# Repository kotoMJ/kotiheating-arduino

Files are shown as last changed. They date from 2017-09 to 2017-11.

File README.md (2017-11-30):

# kotiheating-arduino

IoT KotiHeating project for remote heating control realized with Arduino HW.

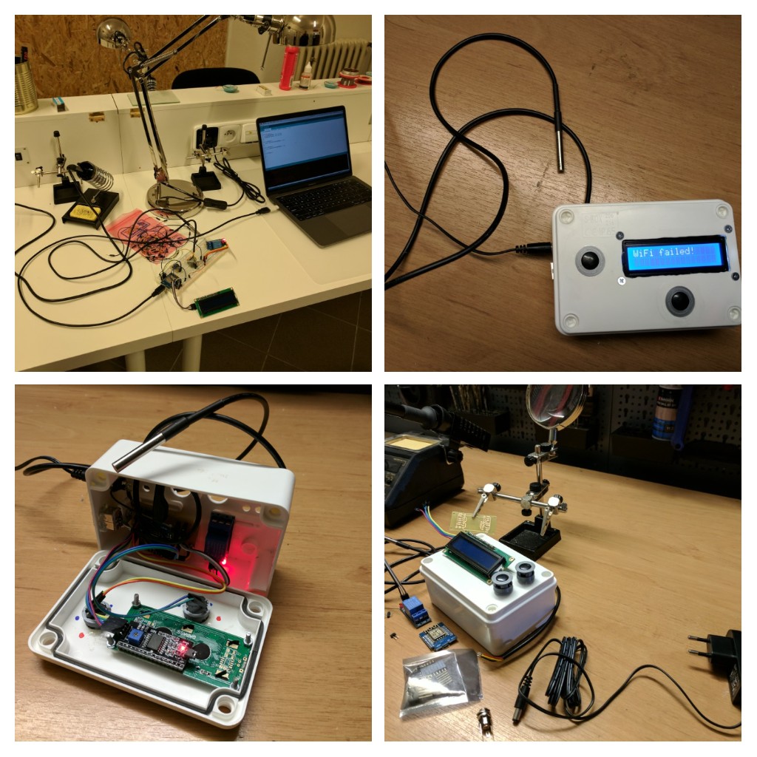
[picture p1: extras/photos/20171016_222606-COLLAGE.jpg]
KoTiHeating


## Functionality

KotiHeating offers 3 heating modes:
1) OFF - heating is set to non-freezing level (5°C)
2) MANUAL - allows set heating level from 18°C to 28°C
3) AUTOMATIC - reads temperature from locally saved matrix

## WiFi Connectivity

KotiHeating exposes following endpoints via WIFI:
- TBD.
- TBD.

## Internet Connectivity

Kotiheating is periodically connecting to server endpoint to update AUTOMATIC matrix 
and to save last known state of the device.

Server matrix can be changed on the server TBD.

Server expose last known state of the KotiHeating via API TBD.

### HTTPS connection

#### Cipher suite supported by device
Current solution is for chip ESP8266.
This chip supports TLS1.1 only and only in these two variants:
1)TLS_RSA_WITH_AES_256_CBC_SHA
2)TLS_RSA_WITH_AES_128_CBC_SHA

You can check your device running this program on it:
 `http.begin("https://www.howsmyssl.com/a/check", "4D 05 9F 78 25 B2 82 98 3A B9 4D 4D 41 71 FA D3 DF C4 65 B9");`

#### Cipher cuite supported by server
Then check which ciphers has been supported by server (kotopeky.cz in my case):
 
`nmap --script ssl-enum-ciphers -p 443 kotopeky.cz`
 
 If you find device's suite in the server's table, everything is ok.
 Otherwise you have to force server to support also device's cipher, or change device to fit server's cipher suite.
 
#### Key Fingerprint
 
If server's and device's cipher match. 
Then start connection using SHA1 fingerprint (look at the safari status bar for example).
In my case it's this:
 
 `http.begin("https://kotopeky.cz/api/kotinode/heating/status","63 FD D7 BB B4 A5 6C 00 57 0F 23 A2 FD 27 15 96 4A C2 4D 99");`

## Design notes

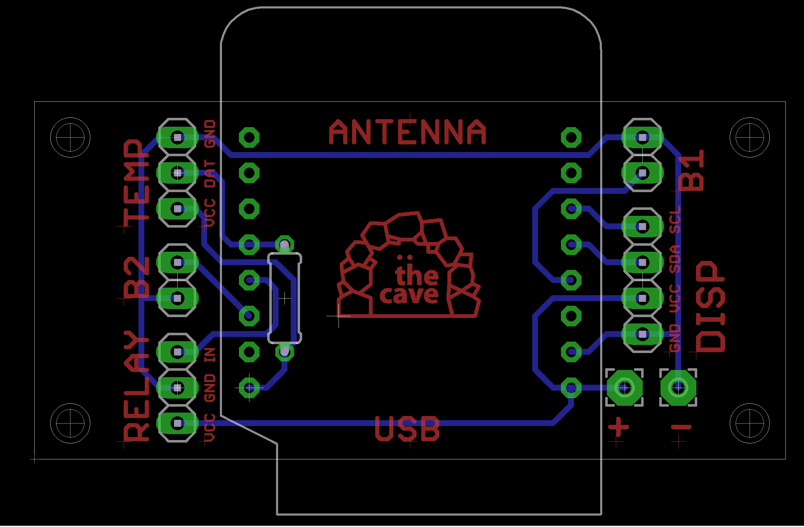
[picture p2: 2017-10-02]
extras/schema/heating_schema.png

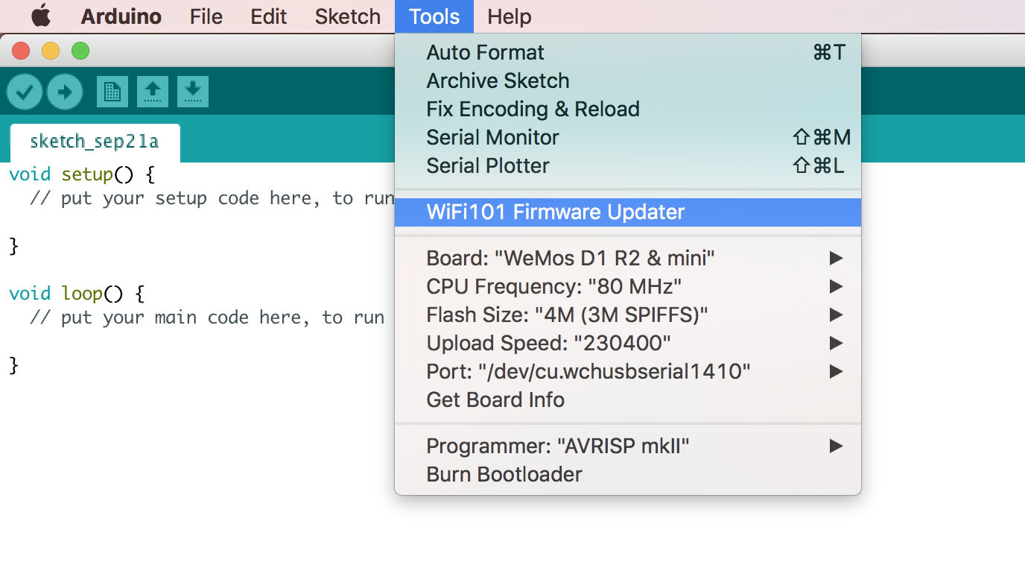
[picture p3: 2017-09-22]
extras/ArduinoToolsSettingsHeating.png

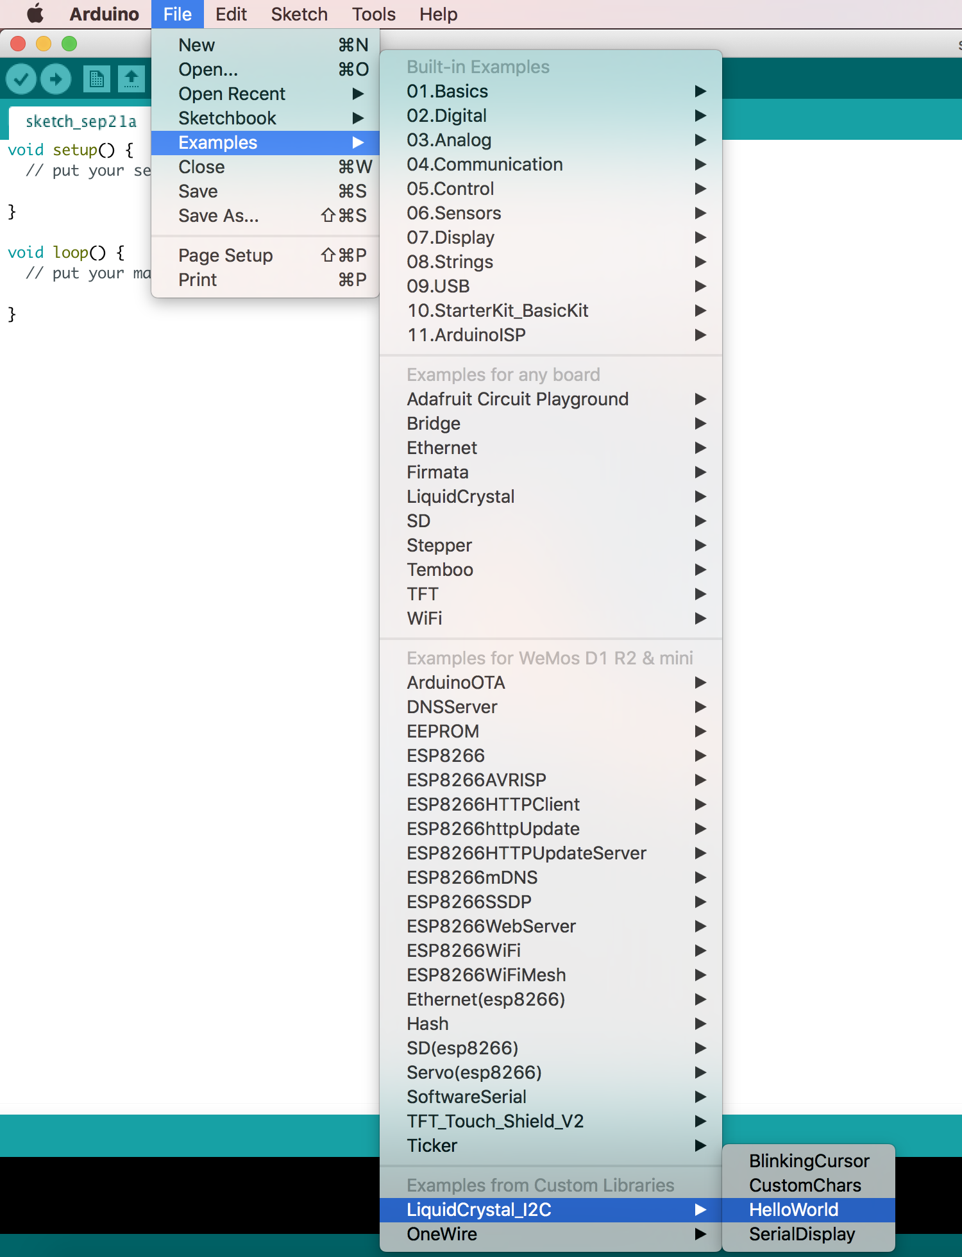
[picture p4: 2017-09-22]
extras/ArduinoExamplesDisplay.png

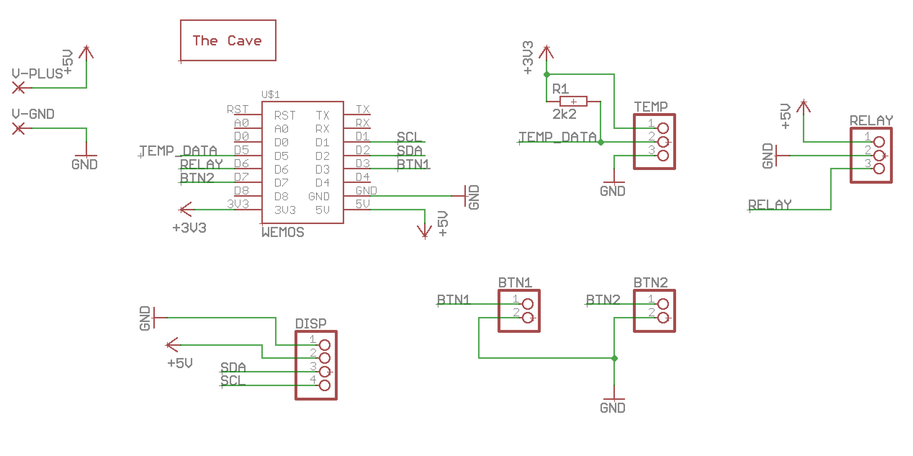
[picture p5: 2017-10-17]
extras/schema/kotiheating-arduino.png

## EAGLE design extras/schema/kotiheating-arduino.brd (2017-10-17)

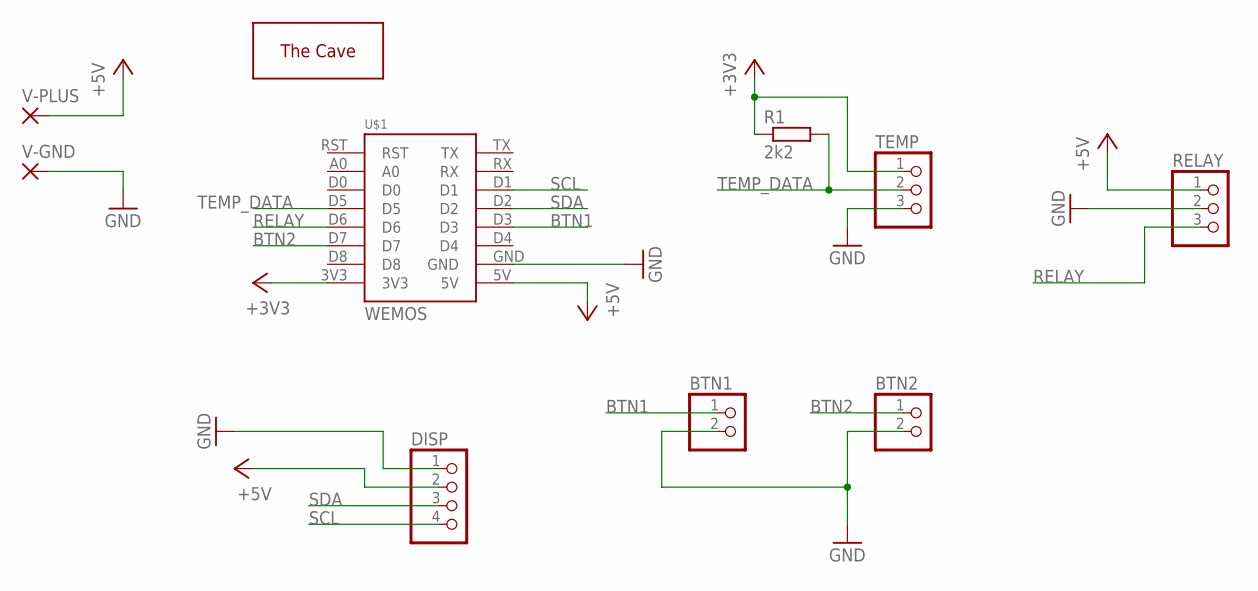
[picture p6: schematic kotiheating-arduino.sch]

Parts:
BTN1, BTN2: PINHD-1X2; 1X02
DISP: PINHD-1X4; 1X04
R1: 2k2; 0207/7
RELAY: PINHD-1X3; 1X03
TEMP: PINHD-1X3; 1X03
U$1: WEMOS
U$2: THECAVE_LOGO_COPPER_SMALL; LOGO_COPPER_SMALL
V-GND: WIREPAD2,54/0,9; 2,54/0,9
V-PLUS: WIREPAD2,54/0,9; 2,54/0,9

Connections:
+3V3: R1.1, TEMP.1, U$1.3V3
+5V: DISP.2, RELAY.1, U$1.5V, V-PLUS.1
BTN1: BTN1.1, U$1.D3
BTN2: BTN2.1, U$1.D7
GND: BTN1.2, BTN2.2, DISP.1, RELAY.2, TEMP.3, U$1.GND, V-GND.1
RELAY: RELAY.3, U$1.D6
SCL: DISP.4, U$1.D1
SDA: DISP.3, U$1.D2
TEMP_DATA: R1.2, TEMP.2, U$1.D5

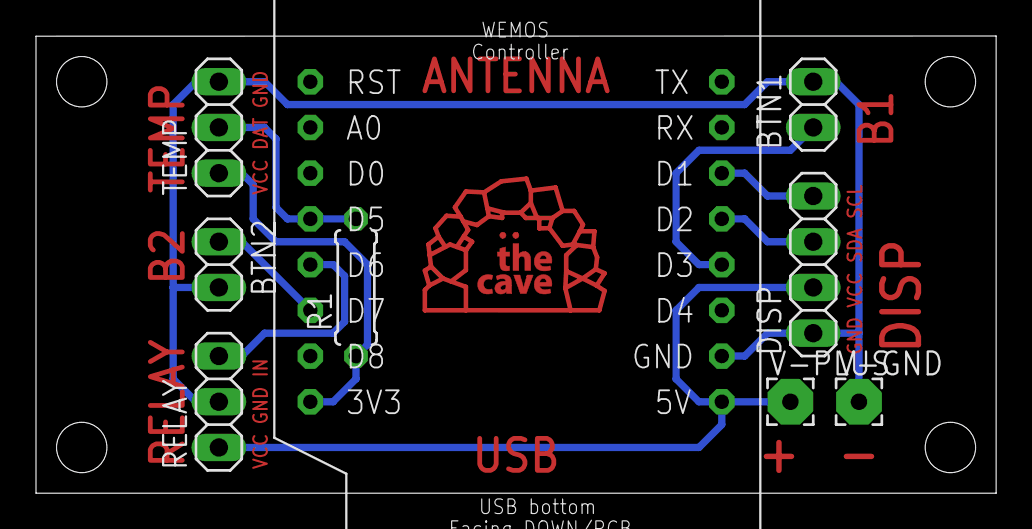
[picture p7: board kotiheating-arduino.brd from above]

Board: 2 copper layers, 53.3 x 25.4 mm, 10 parts (0 on the bottom side), 9 nets.

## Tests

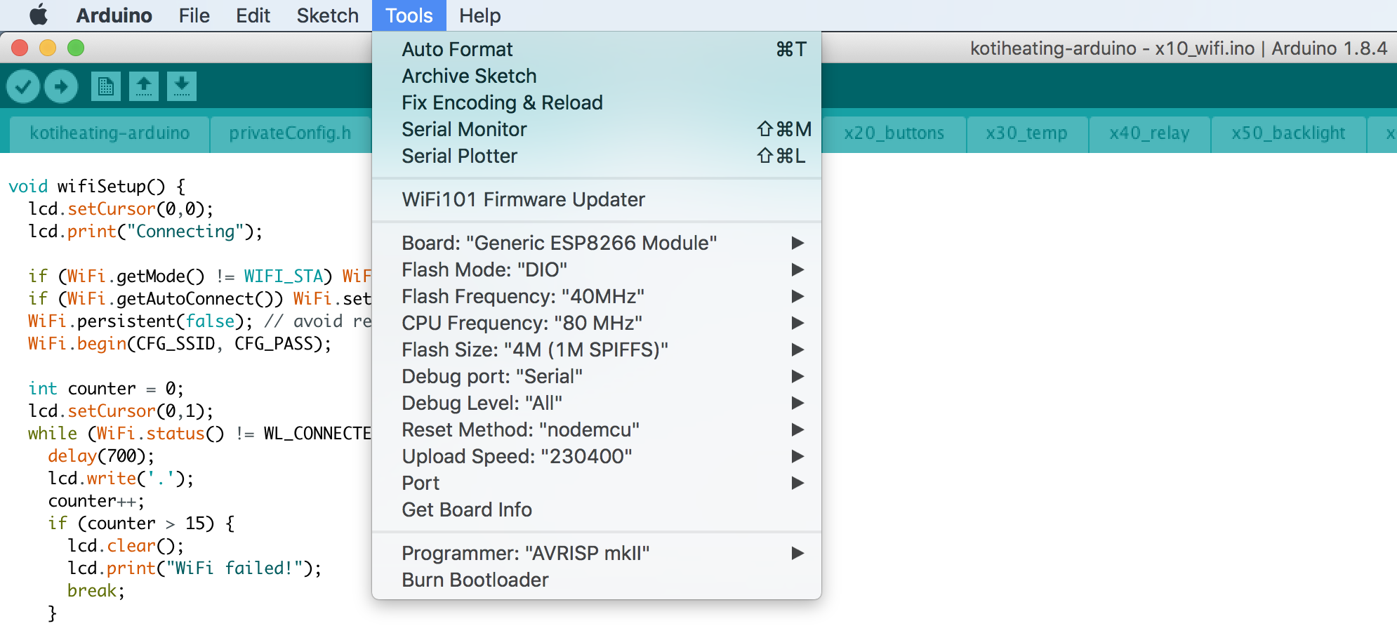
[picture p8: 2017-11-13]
extras/ArduinoToolsSettingsHttpTest.png

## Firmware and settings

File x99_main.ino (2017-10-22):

void btnEvent1() {
  if (backlightRefresh()) return;

  logicModeSwitch();
  displayCb();
}

void btnEvent2() {
  if (backlightRefresh()) return;
  if (logicMode == LOGIC_MODE_MANUAL) {
    logicChangeManualTemp();
    displayCb();
  }
}


void setup() {
  Serial.begin(115200);

  btnSetup();
  relaySetup();
  tempPrepare();
  logicSetHeating(false);

  lcd.begin();
  lcd.backlight();

  wifiSetup();

  otaSetup();
  ntpSetup();
  serverSetup();
  taskNtpSync.enable();
  backlightTask.enableDelayed(0);
  tempTask.enableDelayed(0);
  btnTask.enable();
  logicTask.enable();
  displayTask.enable();
  clientTask.enable();
}

void loop() {
  ArduinoOTA.handle();
  server.handleClient();
  scheduler.execute();
}

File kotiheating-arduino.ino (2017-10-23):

#include <ESP8266WiFi.h>
#include <ESP8266WiFiMulti.h>
#include <WiFiClient.h>
#include <ESP8266WebServer.h>
#include <ESP8266HTTPClient.h>
#include <ESP8266mDNS.h>
#include <WiFiUdp.h>
#include <ArduinoOTA.h>
#include <Wire.h>
#include <LiquidCrystal_I2C.h>
#include <OneWire.h>
#include <TaskScheduler.h>
#include "privateConfig.h"
#include "Arduino.h"
#define TEMP_INVALID 850

#define PIN_RELAY D6
#define PIN_BUTTON1 D3
#define PIN_BUTTON2 D7



Scheduler scheduler;

LiquidCrystal_I2C lcd(0x27, 16, 2);
OneWire ds(D5);

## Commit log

2017-10-02 Add heating schema
2017-10-03 Add eagle files
    [kotel.brd, kotel.sch]
2017-10-17 Rename schema name according to project naming.
    [kotiheating-arduino.brd, kotiheating-arduino.sch]
2017-10-22 Fix client to fully communicate with the server in both sides.
    [kotiheating-arduino.ino, x15_ntp.ino, x91_client.ino]
2017-10-23 Attempt to fix failing SSH connection.
    [x60_logic.ino, x91_client.ino]
2017-11-30 Change of the server's fingerprint.
2018-11-13 Fix offset issue. Set offset of mid europe to be used in winter. Since winter is time to heat, it's more proper solution so far.
    [x15_ntp.ino]
2018-11-21 Adjust request for writing device's status to server.
2019-02-02 Adjust timer.
